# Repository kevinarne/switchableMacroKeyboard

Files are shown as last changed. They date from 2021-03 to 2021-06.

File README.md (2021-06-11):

# Switchable Macro Keyboard
Many programs, such as Inkscape, have some pretty intricate keyboard shortcuts that I find challenging to use regularly, so I've made a macro keyboard that can be switched between different macro keyboards.

At the moment, the code only supports sending static strings, like "Hooray" or "Wow, that's crazy," but eventually it will also support modifier keys like shift and control.

# Components
* Arduino Pro Micro
* 12 x Cherry MX buttons
* 12 x diodes
* 3D printed housing
* 3D printed knob
* LCD Panel
* 7 x 10k ohm resistors
* 1 x rotary encoder
* Micro USB cable
* Custom PCB (see gerber.zip)

# Next Steps
* Encapsulate keyboard logic in an object
* Add long-press detection to keyboard and rotary encoder
* Add screen animations
* Create scripting language for complicated key sequences
* Remove old LCD code

# Programming
To program using the Arduino environment, make sure to set your board to Arduino Leonardo. There are several test sketches in the src/test folder that you can use to test individual components in isolation, but the main sketch is in the src/macroKeyMain folder along with the keyboards.h file that contains the different macro keyboards to be loaded.

If you simply want this to work as a macro keyboard, but with your own commands, you should only have to change the keyboards.h file and upload the code to your Arduino Pro Micro.

Note: the main sketch has no checks on any of the data in keyboards.h. Although the code may compile and upload, **failure to correctly format keyboards.h can result in index out of bounds errors, causing the keyboard to stop working until power cycled.**

You will need to have the following libraries installed:
* Wire.h
* LiquidCrystal_I2C.h
* Keyboard.h

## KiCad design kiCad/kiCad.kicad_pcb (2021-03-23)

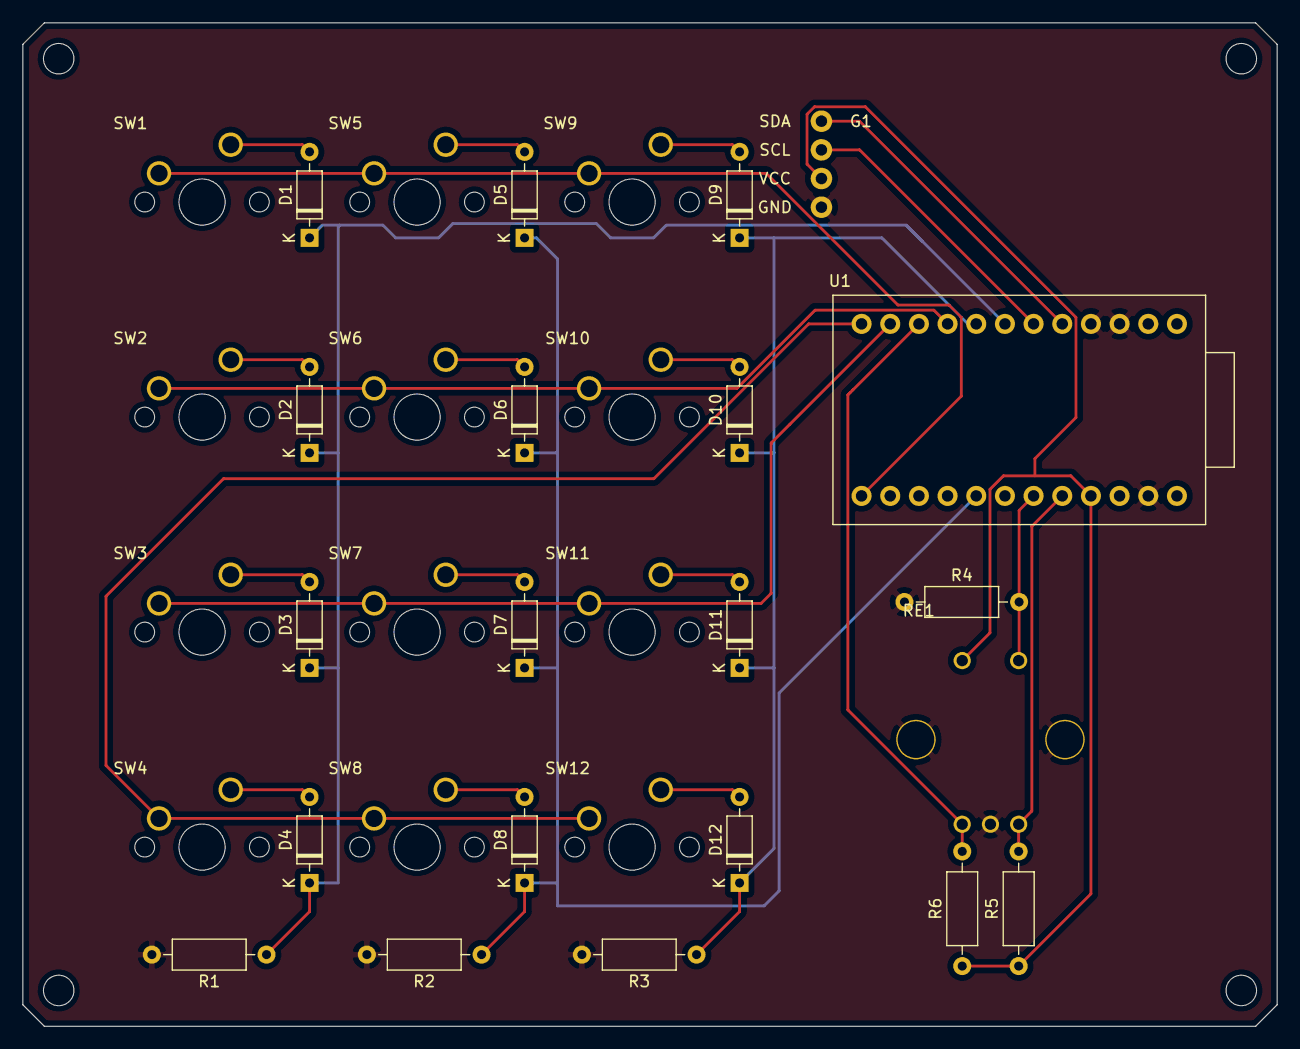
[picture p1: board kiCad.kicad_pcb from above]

Board: 2 copper layers, 111.1 x 88.9 mm, 33 parts (0 on the bottom side), 26 nets.

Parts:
D1, D2, D3, D4, D5, D6, D7, D8, D9, D10, D11, D12: D; D_DO-35_SOD27_P7.62mm_Horizontal
G1: thinOLED
R1, R2, R3, R4, R5, R6: R_US; R_Axial_DIN0207_L6.3mm_D2.5mm_P10.16mm_Horizontal
RE1: RotaryEncoderWButton; REnc-PEC12R-Bourns
SW1, SW2, SW3, SW4, SW5, SW6, SW7, SW8, SW9, SW10, SW11, SW12: SW_Push; cherryMX
U1: ProMicro

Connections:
/COL0: D1.1, D2.1, D3.1, D4.1, R1.1, U1.7
/COL1: D5.1, D6.1, D7.1, D8.1, R2.1, U1.17
/COL2: D9.1, D10.1, D11.1, D12.1, R3.1, U1.8
/EN_CLK: R6.2, RE1.5, U1.10
/ROW0: SW1.1, SW5.1, SW9.1, U1.13
/ROW1: SW2.1, SW6.1, SW10.1, U1.9
/ROW2: SW3.1, SW7.1, SW11.1, U1.11
/ROW3: SW4.1, SW8.1, SW12.1, U1.12
/SCL: G1.2, U1.6
/SDA: G1.1, U1.5
GND: G1.4, R1.2, R2.2, R3.2, R4.1, RE1.4, RE1.6, RE1.7, U1.3, U1.4, U1.23
unnamed: D1.2, SW1.2
unnamed: D2.2, SW2.2
unnamed: D3.2, SW3.2
unnamed: D4.2, SW4.2
unnamed: D5.2, SW5.2
unnamed: D6.2, SW6.2
unnamed: D7.2, SW7.2
unnamed: D8.2, SW8.2
unnamed: D9.2, SW9.2
unnamed: D10.2, SW10.2
unnamed: D11.2, SW11.2
unnamed: D12.2, SW12.2
unnamed: R4.2, RE1.2, U1.19
unnamed: R5.2, RE1.3, U1.20
VCC: G1.3, R5.1, R6.1, RE1.1, U1.21

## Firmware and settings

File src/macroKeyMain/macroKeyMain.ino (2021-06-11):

#include <Wire.h>
#include <LiquidCrystal_I2C.h>
#include <Keyboard.h>
#include "keyboards.h"
#include "MacroKeyboard.h"

LiquidCrystal_I2C lcd(0x27,16,2); // set the LCD address to 0x27 for a 16 chars and 2 line display

#define ENA_PIN A1 //Enable pin that disables keyboard output

#define EN_BUT A2  //Button on rotary encoder
#define EN_CLK 7 //Clock on rotary encoder
#define EN_DAT A3 //Data on rotary encoder

#define KEY_DELAY 30 //In millis
#define EN_DELAY 30 //In millis
#define SWITCH_DELAY 30 //In millis

//Rotary encoder global variables
unsigned long lastSwitch = 0;
unsigned long lastRotation = 0;
volatile int enPosition = 0;
boolean prevClk = false;
boolean prevDat = false;
boolean currentClk = false;
boolean currentDat = false;
boolean encChanged = false;

//Pin numbers for the rows and columns in the keyboard
int rows[] = {10,6,8,9};
int cols[] = {4,A0,5};

//Keeps track of whether a button has been pressed
boolean pressed[4][3] = {{false,false,false},
                         {false,false,false},
                         {false,false,false},
                         {false,false,false}};

//Keeps track of when a button was last pressed for debouncing
unsigned long lastPressed[4][3] = {{0,0,0},
                                   {0,0,0},
                                   {0,0,0},
                                   {0,0,0}};

//Keeps track of buttons to be sent
boolean toBeSent[4][3] = {{false,false,false},
                         {false,false,false},
                         {false,false,false},
                         {false,false,false}};

void setup()
{
  MacroKeyboard board = MacroKeyboard();
  // Setup rows as outputs
  for (int i = 0; i < 4; i++)
  {
    pinMode(rows[i], OUTPUT);
  }
  // Setup cols as inputs
  for (int i = 0; i < 3; i ++)
  {
    pinMode(cols[i], INPUT);
  }

  // Setup ENA_PIN as input
  pinMode(ENA_PIN, INPUT);

  // Setup EN_BUT as input
  pinMode(EN_BUT, INPUT);

  //Setup EN_CLK and EN_DAT as inputs
  pinMode(EN_CLK, INPUT);
  pinMode(EN_DAT, INPUT);

  // Initialize the lcd
  lcd.init();
  lcd.backlight();
  lcd.setCursor(0,0);
  lcd.print(KB_NAMES[0]);

  //Serial.begin(9600);
  Keyboard.begin();
  // Attach interrupt to ENCLK
  attachInterrupt(INT4, readEncoder, CHANGE);
}

void loop()
{
  // Scan for keyboard inputs
  keyboardScan();
  // Check enable pin
  int enabled = digitalRead(ENA_PIN);
  if (enabled)
  {
    // Send buttons to be sent to keyboard
    sendKeys();
  }
  else
  {
    //Serial.println("Disabled");
    // Send buttons to serial?
  }
  if (encChanged)
  {
    updateDisplay();
    encChanged = false;
  }
}

void keyboardScan()
{
  // Iterate through rows
  for (int r = 0; r < 4; r++)
  {
    // Set row to high
    digitalWrite(rows[r], HIGH);
    for (int c = 0; c < 3; c++) // Heh c++
    {
      //Read each column
      int value = digitalRead(cols[c]);
      // Update matrix of pressed buttons
      if (value)// Button is pressed
      {
        // Check the previous value
        if (pressed[r][c]) // If button previously pressed
        {
          // Don't update last pressed
        }
        else // Button was not previously pressed
        {
          // Set pressed to true
          pressed[r][c] = true;
          // Set last pressed to millis()
          lastPressed[r][c] = millis();
          // Set flag for the value to be sent
          toBeSent[r][c] = true;
        }
      }
      else // The button is not pressed
      {
        if (pressed[r][c]) // Button was previously pressed
        {
            // timeExpired is true if enough time has passed since the last pressing
            // Or if the clock has reset
            // This is suspect and hasn't been tested for clock reset

            boolean timeExpired = !(millis()-lastPressed[r][c] < KEY_DELAY);

            if (timeExpired) // Enough time has elapsed since it was pressed
            {
              // Set the pressed value back to false
              pressed[r][c] = false;
            }
         }
      }
    }
    // Set row to low
    digitalWrite(rows[r], LOW);
  }
}

// Sends the keys that are labelled true in the toBeSent matrix
// Updates to false once that cell is sent
void sendKeys()
{
  // Iterate through rows and cols
  for (int r = 0; r < 4; r++)
  {
    for (int c = 0; c < 3; c++)
    {
      if (toBeSent[r][c])
      {
        if (!containsModifiers(KEYBOARDS[enPosition][r][c])) // String is plain text
        {
          String message = KEYBOARDS[enPosition][r][c];
          Keyboard.print(message);
          toBeSent[r][c] = false;
        }
        else // String involves modifier keys
        {
          handleModifiers(KEYBOARDS[enPosition][r][c]);
          toBeSent[r][c] = false;
        }
      }
    }
  }
}

// This function outputs the pressed matrix to the Serial port
// Meant exclusively for debugging
void printMatrixSerial()
{
  Serial.println("Pressed matrix:");
  for (int r = 0; r < 4; r++)
  {
    for (int c = 0; c < 3; c++)
    {
      Serial.print(pressed[r][c]);
      Serial.print("  ");
    }
    Serial.println("");
  }
}

// Function for the rotary encoder interrupt
void readEncoder()
{
  // Read values
  currentClk = digitalRead(EN_CLK);
  currentDat = digitalRead(EN_DAT);

  // Check last switched time
  if (!(millis() - lastRotation < EN_DELAY) && currentClk)
  {
    // Determine which direction it moved
    if (currentClk == currentDat) // Counter clockwise
    {
      enPosition--;
      if (enPosition < 0) // Check for negative position
      {
        enPosition = NUM_KB-1;
      }
    }
    else // Clockwise
    {
      enPosition++;
      if (enPosition >= NUM_KB) // Check for overflow
      {
        enPosition = 0;
      }
    }

    lastRotation = millis();
    // Set flag for main loop to change LCD
    // Note: this is done as a flag because long processes shouldn't be done in interrupts
    encChanged = true;
  }

  // Set to prev to current
  prevClk = currentClk;
  prevDat = prevDat;
}

void updateDisplay()
{
  lcd.clear();
  lcd.print(KB_NAMES[enPosition]);
}


// Checks to see whether the String contains modifier characters
boolean containsModifiers(String testString)
{
  if (testString.indexOf('&') == 3)
  {
    return true;
  }
  return false;
}

void handleModifiers(String values)
{
  String commands = values;
  if (!containsModifiers(commands))
  {
    return;
  }
  // Check for a lacking last &, not terribly elegant
  if (commands[commands.length()] - 1 != '&')
  {
    commands = commands + '&';
  }

  // Run while there are still numbers in the String
  while (commands.length() > 0)
  {
    int commaIndex = commands.indexOf('&');
    // Check whether the index was found (nonnegative)
    if (commaIndex > 0)
    {
      // Find first comma and pull out the number from the substring
      int number = commands.substring(0,commaIndex).toInt();
      if (number < 256 && number > -1)
      {
        // Do the thing with the number
        Keyboard.press(number);
      }
      // Remove the previous number in the String
      commands = commands.substring(commaIndex+1,commands.length());
    }
    else
    {
      break;
    }
  }
  Keyboard.releaseAll();
}

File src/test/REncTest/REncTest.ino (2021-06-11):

// Testing for the rotary encoder dial and switch
// Valuable resource for understanding rotary encoders: https://lastminuteengineers.com/rotary-encoder-arduino-tutorial/

#define EN_CLK 7 // Clock on rotary encoder
#define EN_DAT A3 // Data on rotary encoder

#define EN_DELAY 50 // In millis

unsigned long lastRotation = 0;

volatile int enPosition = 0;

boolean posChanged = false;

boolean prevClk = false;
boolean prevDat = false;

boolean currentClk = false;
boolean currentDat = false;

void setup() 
{
  // Set pins to output/input
  pinMode(EN_CLK, INPUT);
  pinMode(EN_DAT, INPUT);
  
  // Attach on change interrupt to clock
  attachInterrupt(INT4, readEncoder,CHANGE);

  Serial.begin(9600);
}

void loop() 
{
  if(posChanged)
  {
    Serial.println(enPosition);
    posChanged = false;
  }
}

// Function for the interrupt
void readEncoder()
{
  // Read values
  currentClk = digitalRead(EN_CLK);
  currentDat = digitalRead(EN_DAT);
  
  // Check last switched time
  if (!(millis() - lastRotation < EN_DELAY) && currentClk)
  {
    posChanged = true;
    // Determine which direction it moved
    if (currentClk == currentDat) // Counter clockwise
    { 
      enPosition--;
    }
    else // Clockwise
    { 
      enPosition++;
    }

    lastRotation = millis();
  } 
  
  // Set to prev to current
  prevClk = currentClk;
  prevDat = prevDat;
}

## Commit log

2020-04-21 Initial commit. Copied schematic from original design, added some more buttons (need wiring) and removed the header for the rotary encoder. To do: wire the new buttons, change buttons to tactile butt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
    [switchableMacroKeyboard.sch]
2020-04-21 Added blank Arduino files. To do: Add a switch to the input so it can be debugged appropriately.
2020-04-22 Added some pseudo code to source. Connected the switches to the Pro Micro
    [switchableMacroKeyboard.sch]
2020-04-22 Made rotary encoder footprint and symbol. Wired rotary encoder to Pro Micro. Added LCD breakout points. To do: replace switches with tactile switches, add an enable pin (2-pin jumper), and route.
    [switchableMacroKeyboard.sch]
2020-04-22 Changed to tact switches.
    [switchableMacroKeyboard.sch]
2020-04-22 Routed the entire board and added pulldown resistors to the columns. To do: sleep on it and order in the morning.
    [switchableMacroKeyboard.brd, switchableMacroKeyboard.sch]
2020-04-22 Added an enable option to disable all output when broken for debugging purposes. Mitered all of the traces with a 40 mil miter. Changed the corners from filets to chamfers.
    [switchableMacroKeyboard.brd, switchableMacroKeyboard.sch]
2020-04-22 Added gerber files for the boards I ordered.
2020-04-25 Added pin numbers and some pseudocode.
2020-04-26 Addedmore structure to the keyboard scanning, including some digital reads. Added a toBeSent matrix that helps with communication between the keyboardScanning function and main loop. To do: setup the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
2020-04-27 Added details on bringing the first board version up to speed. Added some position variables to macroKeyMain for the rotary encoder.
2020-04-29 Added enable pin debugging.
2020-05-01 Added test scripts for rotary encoder and enable pin. Rotary encoder test script still needs fleshing out. To do: write keyboard test script.
2020-05-01 Wrote keypad test and ran it on the device (passed). To do: add logic to send a key once to the keypad test.
2020-05-01 Folded the keyboard test scripts back into the macroKeyMain script. To do: work on rotary encoder script.
2020-05-02 Switched around visible layers on board for exporting a dxf. Added code loading info to README.md.
    [switchableMacroKeyboard.brd]
2020-05-02 Added lots of detail to encoder test. Got the position to change with a rotation in either direction (can't tell the difference between the two yet), but in serious need of debouncing.
2020-05-02 Added source for rotary encoder info to the top of REncTest.ino.
2020-05-03 Made rotary encoder only trigger when the clock pin is 1. Reduced delay to 50, seems to have helped with the reliability at higher rotation speeds.
2020-05-03 Integrated the rotary encoder code in macroKeyMain.
2020-05-05 Added I2C header for LCD panel. Rearranged pinouts to open up I2C pins on the Pro Micro. To do: add labels to I2C bus and reroute board.
    [switchableMacroKeyboard.brd, switchableMacroKeyboard.sch]
2020-05-06 Partially rerouted board with several pins moved around on the microcontroller for ease of routing. To do: route columns on bottom layer.
    [switchableMacroKeyboard.brd, switchableMacroKeyboard.sch]
2020-05-25 Added a header file to hold all of the keyboards. Added an LCD test that works.
    [switchableMacroKeyboard.brd, switchableMacroKeyboard.sch]
2020-05-25 Fixed all of the pinouts to reflect the new board layout. Adjusted the rotary encoder test to represent the new pins as well.
    [REncTest.ino, macroKeyMain.ino]
2020-05-25 Integrated keyboard, rotary encoder, and header file. To do: add LCD code to display keyboard name, create language for sending unusual key presses together.
2020-05-25 Reformatted a lot of the code, adding spacing to comments and moving curly brackets around.
2020-05-27 Updated README.md. Moved LCD panel control to a dedicated function in case I change to a different display panel at some point. Updated gerber file to reflect the newest version of the boards.
2020-05-31 Integrated String parsing to allow for modifier keys. Finally hooked up the actual Keyboard library and found it all works. To do: make a new enclosure including the LCD panel, code for the keyboards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
2020-06-05 Switched the buttons to Cherry MX Blues, but found this may require a bigger board, mostly length-wise. Moving the diodes out of the way of the key has cramped things. To do: adjust board dimensions 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
    [switchableMacroKeyboard.brd, switchableMacroKeyboard.sch]
2020-06-10 Adjusted the size of the board and rerouted.
    [switchableMacroKeyboard.brd, switchableMacroKeyboard.sch]
2020-07-06 Moved the Pro Micro board up to reduce interference with the key switches. Adjusted routing accordingly. Ordered this version in green.
    [switchableMacroKeyboard.brd]
2020-07-11 Changed footprints for Cherry MX keys to use holes rather than circles on the Dimension layer due to an issue at the board manufacturer.
    [switchableMacroKeyboard.brd, switchableMacroKeyboard.sch]
2020-07-16 Updated Cherry foot print to fix holes too small for the pins.
    [switchableMacroKeyboard.brd, switchableMacroKeyboard.sch]
2020-07-16 Adjusted routing to allow for the changed switch footprint.
    [switchableMacroKeyboard.brd]
2021-03-19 Started conversion from Eagle to KiCAD. Created rudimentary rotary encoder schematic symbol and footprint based on previous Eagle iteration. Created new schematic symbol for Pro Micro using a more fu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
    [kiCad.sch]
2021-03-19 Added footprint for Pro Micro, next is the footprint for the keys.
2021-03-21 Finished schematic sans OLED screen, generated net list, placed components on board.
    [kiCad.kicad_pcb, kiCad.sch]
2021-03-22 Board routed but missing OLED screen, corner chamfers, mounting holes, logo, and switch footprint fix.
    [kiCad.kicad_pcb]
2021-03-22 Updated the switch footprints, chamfered corners, added mounting holes. Still need to add logo, but then it'll be ready for manufacturing.
    [kiCad.kicad_pcb, kiCad.sch]
2021-03-23 Added logo to solder mask layer (will show the underlying copper fill there). Sending out for manufacturing.
    [kiCad.kicad_pcb]
2021-03-23 Added KiCad-generated gerbers for this iteration of the macro keyboard PCB.
2021-03-23 Removed old Eagle files.
    [switchableMacroKeyboard.brd, switchableMacroKeyboard.sch]
